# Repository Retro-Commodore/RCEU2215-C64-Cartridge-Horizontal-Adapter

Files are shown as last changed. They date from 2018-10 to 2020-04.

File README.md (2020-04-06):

# RCEU2215 - C64 Cartridge Horizontal Adapter
Cartridge vertical to horizontal adapter, i.e. for C128DCR and 1541 Ultimate

This is an adapter I created for my Commodore 128 DCR and 1541 Ultimate 2(+).
I got annoyed that the C128 would reset by cables and the back wall, on the reset switch of any cart with a reset button, due to it's limited space up against the back wall. 
Also the IEC cable connectors would cross tightly and strain the connectors on both IEC and U2 ports. 
The U2+ IEC got moved back in this new design, but not enough, and now the tape connector + audio connectors are in the way.

The result was to make this adapter, and the items below fixes that problem

* 2 (nylon) standoffs 
* 44pin Edge connector 2.54mm pitch, straight

Standoffs and connector can be found on ebay, or perhaps your favorite local store.

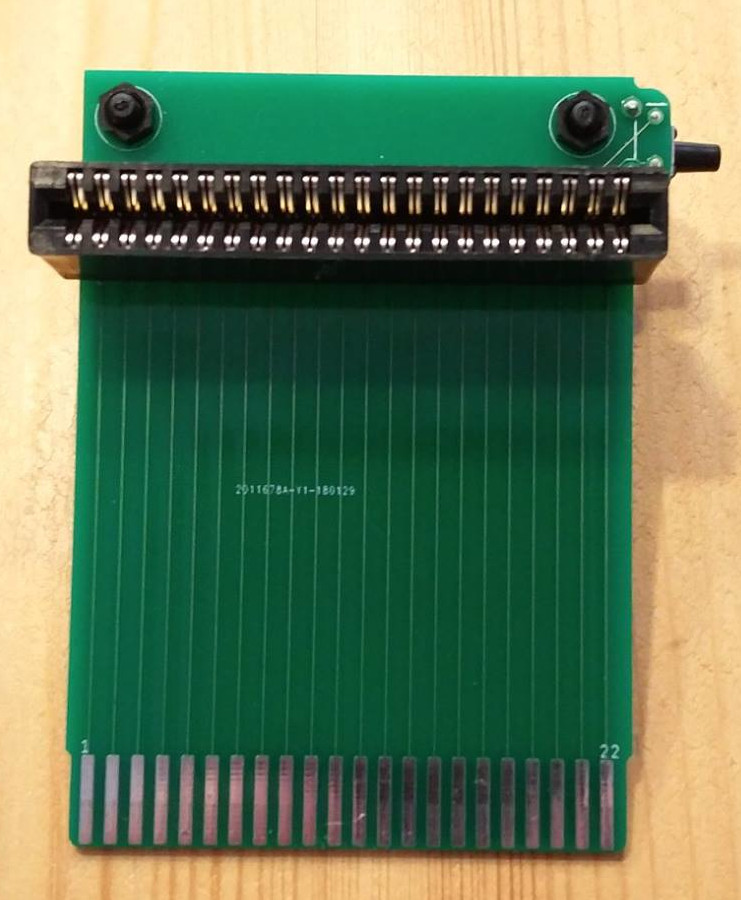
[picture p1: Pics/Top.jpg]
C64 Cartridge Horizontal Adapter


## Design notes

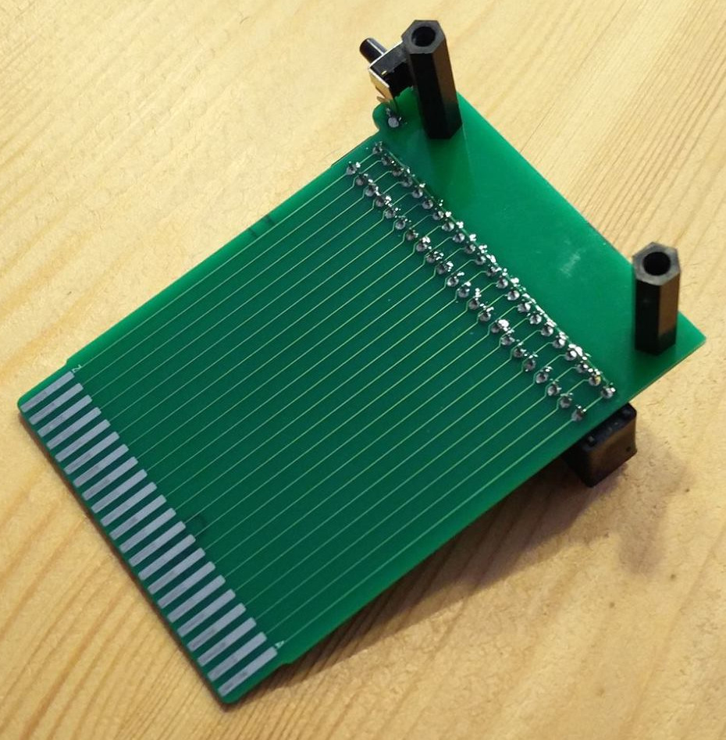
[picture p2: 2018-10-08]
Pics/Bottom.jpg

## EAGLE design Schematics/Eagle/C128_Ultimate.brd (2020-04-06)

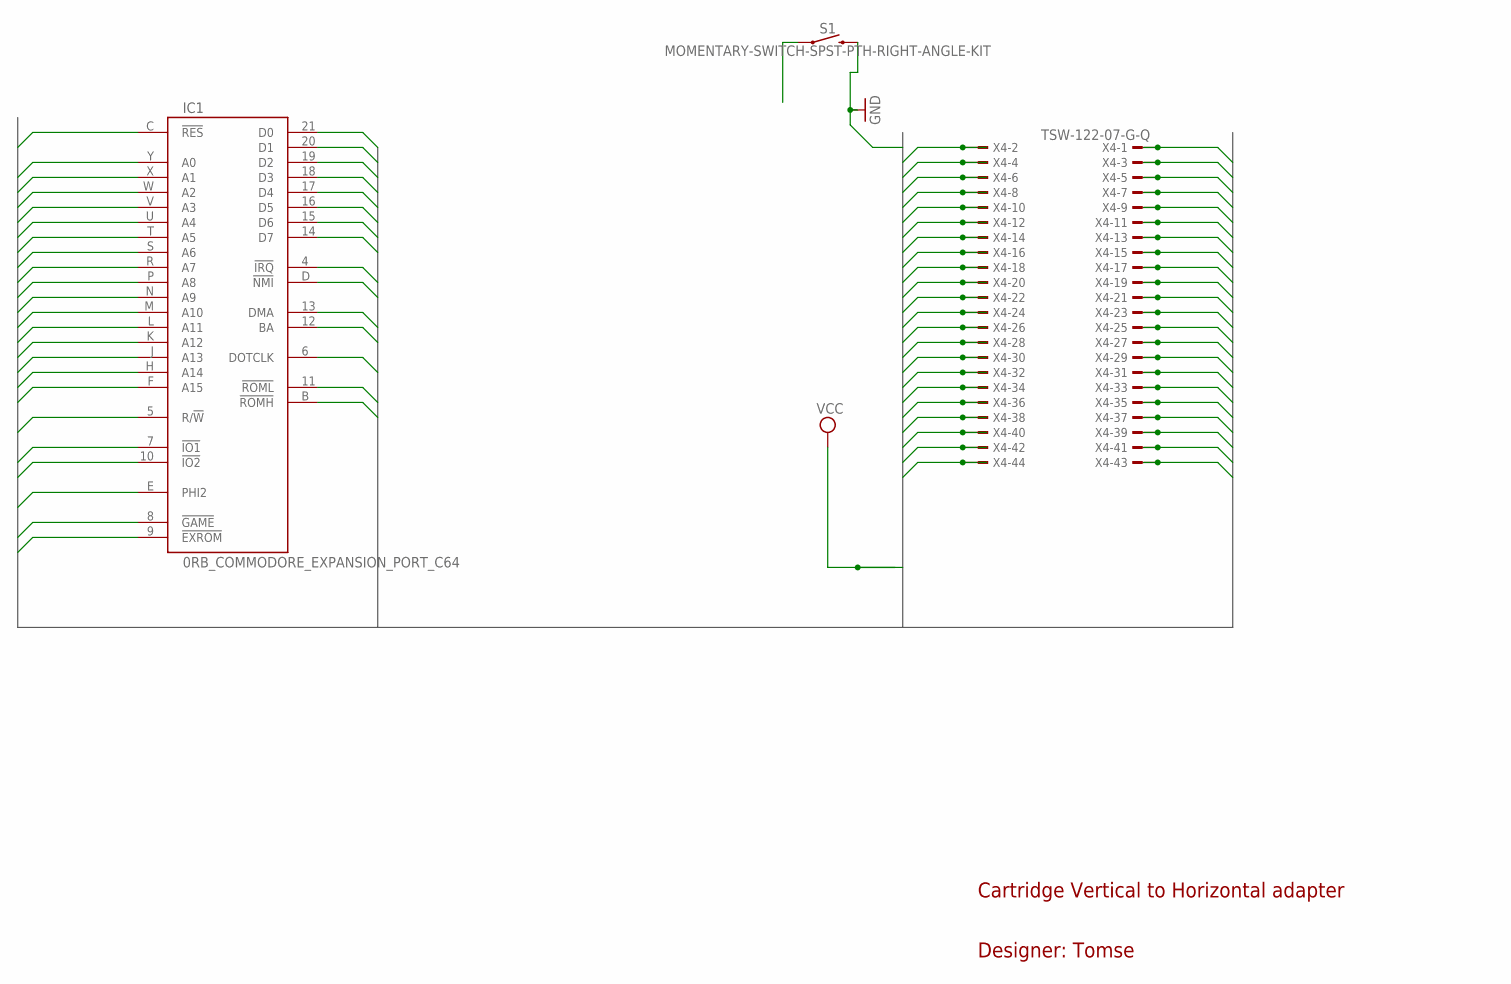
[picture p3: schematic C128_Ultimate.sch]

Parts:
IC1: 0RB_COMMODORE_EXPANSION_PORT_C64; 0RB_COMMODORE_MA100-22-2
S1: MOMENTARY-SWITCH-SPST-PTH-RIGHT-ANGLE-KIT; TACTILE_SWITCH_PTH_RIGHT_ANGLE_KIT
X4: TSW-122-07-G-Q; TSW-122-XX-G-Q

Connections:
!DMA: IC1.13 (DMA), X4.26
!EXROM: IC1.9 (!EXROM), X4.18
!GAME: IC1.8 (!GAME), X4.16
!IO1: IC1.7 (!IO1), X4.14
!IO2: IC1.10 (!IO2), X4.20
!IRQ: IC1.4 (!IRQ), X4.8
!NMI: IC1.D (!NMI), X4.7
!RES: IC1.C (!RES), S1.1, X4.5
!ROMH: IC1.B (!ROMH), X4.3
!ROML: IC1.11 (!ROML), X4.22
A0: IC1.Y (A0), X4.41
A1: IC1.X (A1), X4.39
A2: IC1.W (A2), X4.37
A3: IC1.V (A3), X4.35
A4: IC1.U (A4), X4.33
A5: IC1.T (A5), X4.31
A6: IC1.S (A6), X4.29
A7: IC1.R (A7), X4.27
A8: IC1.P (A8), X4.25
A9: IC1.N (A9), X4.23
A10: IC1.M (A10), X4.21
A11: IC1.L (A11), X4.19
A12: IC1.K (A12), X4.17
A13: IC1.J (A13), X4.15
A14: IC1.H (A14), X4.13
A15: IC1.F (A15), X4.11
BA: IC1.12 (BA), X4.24
D0: IC1.21 (D0), X4.42
D1: IC1.20 (D1), X4.40
D2: IC1.19 (D2), X4.38
D3: IC1.18 (D3), X4.36
D4: IC1.17 (D4), X4.34
D5: IC1.16 (D5), X4.32
D6: IC1.15 (D6), X4.30
D7: IC1.14 (D7), X4.28
DOTCLK: IC1.6 (DOTCLK), X4.12
GND: IC1.1 (GND), IC1.22 (GND), IC1.A (GND), IC1.Z (GND), S1.2, X4.1, X4.2, X4.43, X4.44
PHI2: IC1.E (PHI2), X4.9
R!W: IC1.5 (R/!W), X4.10
VCC: IC1.2 (VCC), IC1.3 (VCC), X4.4, X4.6

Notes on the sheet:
Cartridge Vertical to Horizontal adapter
Designer: Tomse

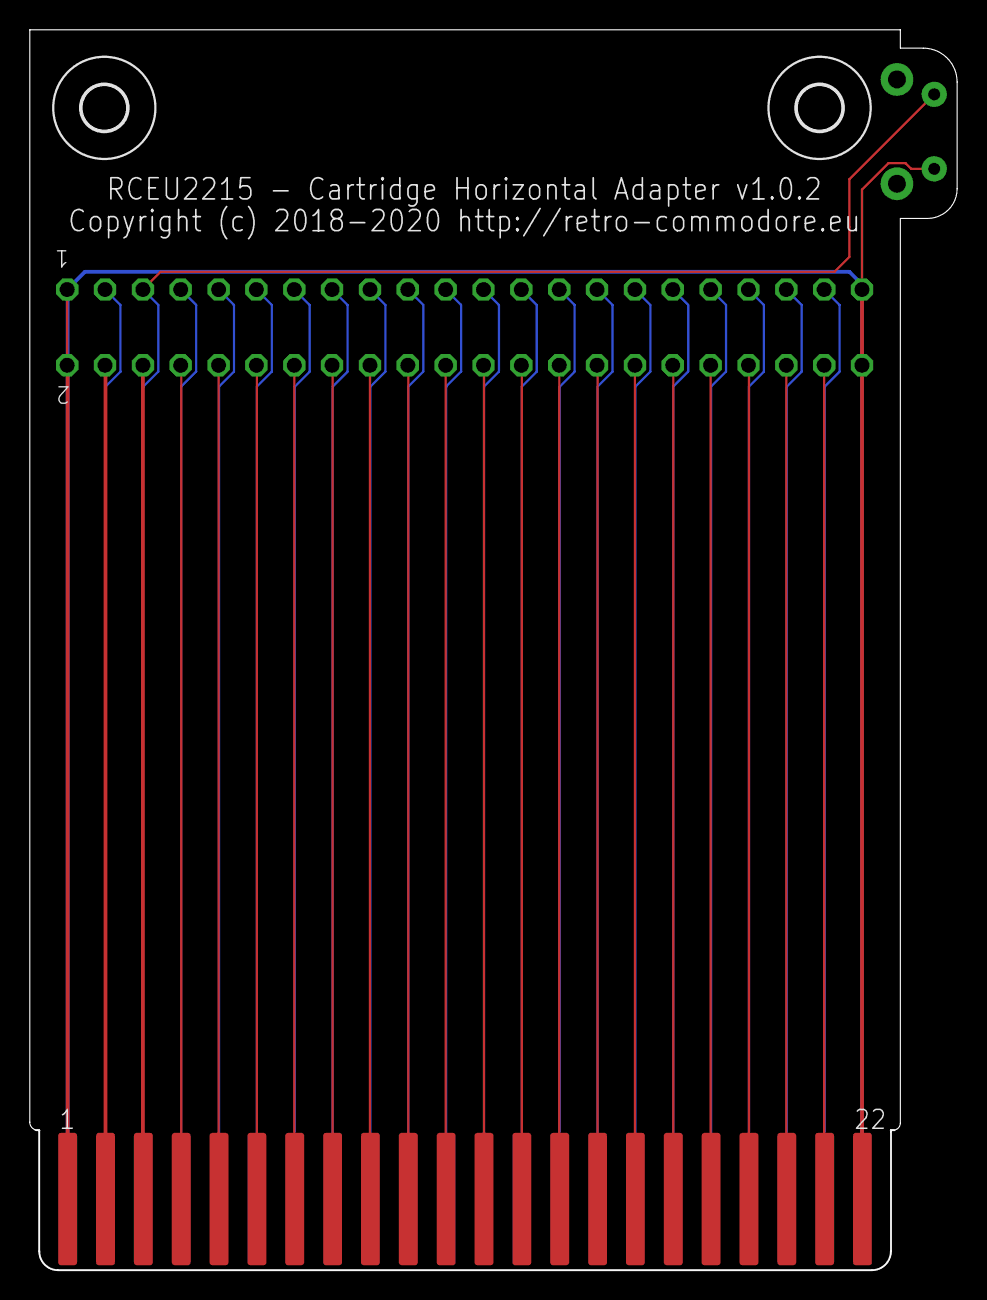
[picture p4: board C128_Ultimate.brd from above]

Board: 2 copper layers, 62.2 x 83.2 mm, 5 parts (1 on the bottom side), 40 nets.

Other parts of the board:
U$1, U$2: 3,0

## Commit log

2018-10-09 Update Hardware/Eagle/C128_Ultimate.brd
    Properly moved reset button to bottom side
    [C128_Ultimate.brd]
2018-10-09 Update Hardware/Eagle/C128_Ultimate.sch
    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
    [C128_Ultimate.sch]
2018-10-09 Update Hardware/Eagle/C128_Ultimate_2018-10-09_CAM_Files.zip
    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
2018-10-09 Update Hardware/Eagle/C128_Ultimate_2018-01-28_CAM_Files.zip
    removed old cam files - improperly set reset button
2020-04-06 Cosmetic changes
    [C128_Ultimate.brd, C128_Ultimate.sch]

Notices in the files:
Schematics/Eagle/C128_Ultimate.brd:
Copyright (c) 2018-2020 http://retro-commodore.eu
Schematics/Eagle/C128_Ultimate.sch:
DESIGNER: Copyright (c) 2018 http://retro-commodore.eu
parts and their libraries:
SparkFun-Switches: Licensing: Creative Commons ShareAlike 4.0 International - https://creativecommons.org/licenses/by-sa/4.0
